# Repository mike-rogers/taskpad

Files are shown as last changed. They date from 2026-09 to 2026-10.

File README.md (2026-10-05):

# TaskPad

**[Project page & browser flasher](https://mike-rogers.github.io/taskpad/)** ·
install the integration via HACS custom repository
(`https://github.com/mike-rogers/taskpad`) · printable case in [`stl/`](stl/) ·
MIT licensed

A small desk gadget that nags you (politely) about periodic chores — change
the furnace filter, dose the dog, swap smoke detector batteries. Home
Assistant is the source of truth; this device displays what's coming due and
lets you check things off with a button.

The device talks MQTT and announces itself with MQTT discovery, so it appears
in HA as a proper device (with online/offline connectivity and a
last-completed-task sensor) — no API tokens involved.

Hardware:

- SparkFun Pro Micro ESP32-C3
- 2.8" 240x320 ST7789 TFT (SPI)
- Two momentary buttons, and optionally the Adafruit ANO rotary encoder on
  its I2C seesaw adapter (product 5740)

## Wiring (defaults, changeable in menuconfig)

| LCD pin | ESP32-C3 GPIO |
|---|---|
| VCC | 3V3 |
| GND | GND |
| SCL / SCK | 6 |
| SDA / MOSI| 7 |
| CS | 10 |
| DC | 4 |
| RES / RST | 5 |
| BLK | 3 |

| Button | GPIO |
|---|---|
| Done (complete) | 1 → button → GND |
| Down (select) | 9 (onboard BOOT button) |

| ANO adapter (STEMMA QT) | ESP32-C3 GPIO |
|---|---|
| VIN (red) | 3V3 |
| GND (black) | GND |
| SDA (blue) | 0 |
| SCL (yellow) | 2 |

The encoder is detected at boot; without it the device runs on the two
buttons alone. Wheel and up/down move the selection, center press
completes, center long-press marks blocked.

## Home Assistant setup

Terminology note: recent HA renamed "Add-ons" to **Apps**, and the config
directory File Editor shows is **`homeassistant/`** (formerly `/config` —
same place, new name; HA core itself still calls it `/config` internally,
which is why file paths below use that form).

Tasks live in a native HA **to-do list**, so adding and editing chores
happens on the To-do sidebar page — no YAML edits per task. Completions are
appended to a permanent log file, `/config/taskpad_history.log`.

1. Install the **File Editor** app (Settings → Apps → App Store) so you can
   edit YAML files, and the **Mosquitto broker** app if it isn't already
   installed. Once Mosquitto is running, Settings → Devices & Services will
   offer to set up the MQTT integration — accept it.
2. Create a dedicated HA user (e.g. `taskpad`) under Settings → People →
   Users; the device logs into the broker with it.
3. In File Editor, open `configuration.yaml` (in the root `homeassistant/`
   directory) and add this block at the top, above `default_config:`:

   ```yaml
   homeassistant:
     packages: !include_dir_named packages
     allowlist_external_dirs:
       - /config
   ```

   (The allowlist is what permits the File integration to write the history
   log. It must be in place, and HA restarted, BEFORE you set up the File
   integration in step 6 — the integration validates the path when you add
   it, and rejects it with "Access to the selected file path is not
   allowed" otherwise.)
4. Create the `packages` folder first using File Editor's New Folder button —
   naming a new file `packages/taskpad.yaml` does NOT auto-create the folder;
   it errors instead. Then create `taskpad.yaml` inside it and paste in the
   contents of `ha/taskpad.yaml` from this repo.
5. Validate with Developer Tools → YAML → Check configuration, then restart
   HA.
6. Add two integrations under Settings → Devices & Services → Add
   integration:
   - **Local to-do**: create a list named `TaskPad`. Confirm its entity id
     is `todo.taskpad` (Developer Tools → States); the package references
     that id.
   - **File**: choose the notification service type, file path
     `/config/taskpad_history.log`, timestamps enabled. The integration
     names the entity generically (`notify.file`), so rename it: Settings →
     Devices & Services → Entities → `notify.file` → settings (gear icon) →
     set Entity ID to `notify.taskpad_history`.
7. Add your chores on the **To-do** sidebar page: name, first due date, and
   the repeat interval in the description field — `interval: 90` (days),
   `interval: 2w`, `interval: 3m`, or `interval: 1y`. Anything missing or
   unparseable falls back to 30 days.

## Custom integration (replaces the package)

`custom_components/taskpad/` supersedes the YAML package, Local to-do, and
File integration: an integration-owned `todo.taskpad` entity with
structured intervals, direct MQTT handling (no automations), the same
completion-relative rescheduling and history log, a `taskpad.complete`
service, and a `taskpad_completed` event. Ticking the checkbox on the
To-do card runs the full completion flow (unlike the package setup).

The integration also serves a dashboard card: add a card of type
`custom:taskpad-card` to any dashboard for the full editor — task list
with urgency colors, complete/block/edit buttons, and a create/edit form
(name, first due date, periodicity value + days/weeks/months, and the
dependency task spawned on long-press). The same operations exist as
typed services (`taskpad.add_task`, `taskpad.update_task`,
`taskpad.block`, `taskpad.complete`) for automations and Developer Tools.

Install: copy the folder to `custom_components/taskpad/` in the HA config
directory, restart HA, then Settings → Devices & Services → Add
integration → TaskPad. Use the import field to pull your open items from
the existing list, then delete the old Local to-do list and remove the
package's `script:`/`automation:` blocks (double handlers = double
successors). Tip: the Samba share app makes copying the folder a
drag-and-drop from a mounted network share.

The package setup steps below describe the pre-integration architecture;
they're kept as documentation of the fallback path, not required setup.

## Build & flash

```sh
idf.py set-target esp32c3
idf.py menuconfig   # TaskPad Configuration: Wi-Fi + pins (broker config
                    # is pushed by the HA integration during adoption)
idf.py build flash monitor
```

Broker setup happens over the network, not at compile time: the device
advertises `_taskpad._tcp` via mDNS and serves a small local API
(`GET /api/info`, `POST /api/config`). Home Assistant discovers it
("New device found: TaskPad"), and the integration's adoption step pushes
the MQTT broker URI and credentials, which the device stores in NVS and
reboots onto. Re-adopt any time (credential rotation, new broker) via the
integration's Configure → "Adopt device" menu. Use an IP address for the
broker URI — the device can't resolve `.local` names.

`sdkconfig` holds your Wi-Fi password, and is gitignored.

## Behavior

- HA publishes the task list to the retained `taskpad/tasks` topic whenever
  the to-do list changes (plus hourly, to catch due-date edits); the device
  gets updates instantly and current state on every reconnect — no polling.
- Shows tasks due within 14 days (configurable); overdue tasks always show.
- Row color by urgency: green → yellow (≤7 days) → orange (≤2 days) →
  red (overdue).
- Long-pressing Done (~1.5s) marks the selected task **blocked**: a linked
  one-shot "Prep: …" item is created due today (rename it in HA to what the
  prep actually is, e.g. "Call vet about flea meds"), and the blocked task
  renders muted on the display. Completing the prep task auto-unblocks the
  parent; completing the parent directly auto-closes the orphaned prep.
- BOOT moves the selection; the Done button publishes to `taskpad/complete`,
  which runs `script.taskpad_complete`: the to-do item is closed out (it
  stays in the completed pile as a visual record), a successor item is
  created due **completion date + interval**, and a timestamped line is
  appended to `/config/taskpad_history.log` — the permanent record, immune
  to HA's ~10-day recorder purge.
- To complete a chore from HA instead of the device, run
  `script.taskpad_complete` (e.g. from a dashboard button) with the item's
  name. Ticking the checkbox on the To-do page completes the item WITHOUT
  scheduling the next occurrence or logging.
- Availability via MQTT last-will: unplug the device and its Connectivity
  entity in HA goes off.

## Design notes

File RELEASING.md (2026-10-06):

# Releasing TaskPad

## Firmware release (public, via CI)

1. Bump `TASKPAD_FW_VERSION` in `main/fw_version.h`.
2. Commit, then tag and push:

   ```sh
   git tag vX.Y.Z
   git push origin main --tags
   ```

3. CI (`.github/workflows/firmware.yml`) builds against ESP-IDF v6.0 and
   attaches three assets to the GitHub release:
   - `taskpad.bin` — the OTA application image
   - `taskpad-factory.bin` — esptool-merged full-flash image
   - `taskpad.zip` — the integration **with the matching firmware baked
     in**; HACS installs this (`zip_release` in `hacs.json`), so HACS
     users get device updates on the HA device page automatically after
     updating the integration
4. The release publish triggers `.github/workflows/pages.yml`, which
   redeploys the project page and browser flasher with the new factory
   image. (The binary is copied into the Pages artifact deliberately:
   GitHub release assets don't send CORS headers, so ESP Web Tools can't
   fetch them cross-origin.)

## Updating your own device (local dev builds, no CI)

For a HACS-managed install, the normal path is: update TaskPad in HACS →
restart → Install on the device page. The steps below are for pushing a
locally built firmware without cutting a release:

1. `idf.py build`
2. `./scripts/release_firmware.sh` — stages `taskpad.bin` + `version.txt`
   into `custom_components/taskpad/firmware/`
3. Copy `custom_components/taskpad/firmware/*` to the HA config share
   (plain `cp`, not Finder — the Samba add-on vetoes `._*` metadata files
   and Finder copies fail with error -8062).
4. Home Assistant → TaskPad device page → the Firmware entity offers the
   update (poll is ~15 min; force with the `homeassistant.update_entity`
   action) → Install. The device pulls, flashes the idle OTA slot, and
   reboots; a boot that never reaches MQTT rolls back automatically.

## Integration release

1. Bump `version` in `custom_components/taskpad/manifest.json` **and**
   `VERSION` in `custom_components/taskpad/const.py` (they must match —
   the versioned Lovelace resource URL busts card caches).
2. Local install: copy the changed files to the share and restart HA.
3. HACS installs pick up new tags/default-branch commits via HACS's
   normal update flow.

## Invariants worth knowing

- Firmware and integration versions are independent; the update entity
  compares the device's reported version (retained `taskpad/status`)
  against `firmware/version.txt`, and only offers an update when the
  served `taskpad.bin` actually exists next to it.
- The OTA slots are 1984KB each and the image is ~1.8MB (~10% headroom).
  Budget flash before adding large components.
- A commit that shouldn't trigger the firmware CI can include `[skip ci]`
  in its message.

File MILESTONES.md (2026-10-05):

# TaskPad Milestones

Each milestone leaves the whole system working end-to-end before the next
begins.

## M0 — Baseline (done, 2026-09-24)

ESP-IDF firmware (ESP32-C3 + ST7789, LVGL, MQTT) plus a Home Assistant YAML
package: Local to-do list backend, completion-relative rescheduling,
permanent history log via the File integration, MQTT discovery device.
Working: button → todo close-out → successor → history line → display
refresh.

## M1 — Custom integration core (done, 2026-09-24)

Replace the YAML package, Local to-do, and File integration with
`custom_components/taskpad/`:

- [x] Integration-owned `todo.taskpad` entity backed by `.storage`
      (structured `interval_days` per item instead of description-string
      parsing being the source of truth; `interval: N[d|w|m|y]` in the
      description remains the input method from the To-do card)
- [x] Config flow (topic prefix, log path, default interval) + options flow
- [x] MQTT: subscribe `taskpad/complete` directly, publish retained
      `taskpad/tasks` on every change (no automations)
- [x] Completion logic in Python: close item, create successor at
      completion date + interval, append history line, fire
      `taskpad_completed` bus event (logbook visibility)
- [x] Ticking the checkbox in the To-do card triggers the SAME completion
      flow (the entity intercepts the status change — the old "don't touch
      the checkbox" rule dies here)
- [x] `taskpad.complete` service (name or uid)
- [x] One-time import from the existing Local to-do list
- [x] Clean uninstall: `async_remove_entry` deletes storage and clears the
      retained tasks topic
- [x] Migration: after verification, remove the package automations/script
      and the Local to-do list

Firmware: unchanged.

## M2 — Blocked / prerequisite tasks (done, 2026-09-24)

- [x] Firmware: long-press detection on Done (and later the ANO center
      button); publishes `{"task_id": ...}` to `taskpad/blocked`
- [x] Integration: creates a linked one-shot prep item ("Prep: <name>", due
      today, no interval), marks the parent blocked, stores the link by uid
- [x] Completing the prep item auto-unblocks the parent; completing the
      parent directly auto-closes the orphaned prep item
- [x] Published task list gains a `blocked` flag; device renders blocked
      items distinctly
- [x] History log records blocked/unblocked transitions

## M2.5 — Task editor: typed services + custom card (done, 2026-09-26)

- [x] Structured periodicity stored as value + unit (days/weeks/months);
      per-task dependency text (`prep_text`) used as the spawned prep item's
      name; storage migration from interval_days-only items
- [x] Services with typed selectors: `taskpad.add_task` (name, first due
      date defaulting to today + period, value + unit, dependency text),
      `taskpad.update_task`, `taskpad.block`
- [x] Task metadata exposed as `todo.taskpad` attributes for the frontend
- [x] `custom:taskpad-card` (vanilla JS, served + auto-registered by the
      integration): task list with urgency colors, blocked/prep rendering,
      complete/block/edit buttons, and a create/edit form with the fields
      above, prefilled on edit
- [x] Legacy `interval:` description parsing retained as fallback input

## M3 — Discovery & adoption (done, 2026-09-26)

- [x] Firmware: mDNS advertisement (`_taskpad._tcp`, TXT: id + version) and
      a small local HTTP endpoint that accepts broker config on first boot;
      config persisted to NVS
- [x] Integration: zeroconf discovery in the manifest → "New device found"
      card → config flow pushes broker credentials to the device
- [x] Remove Wi-Fi/broker secrets from menuconfig (Wi-Fi still via
      menuconfig until M4)
- [x] Remove device-side MQTT discovery configs (the integration owns the
      device registration); firmware sheds the discovery payloads

Note: adoption verified working on first try. Auto-discovery initially
appeared broken; a Linux host resolving both homeassistant.local and the
device disproved the network-filtering theory (the Mac's failures were
macOS Local Network permission gating) and pointed at the config flow
reading the removed ZeroconfServiceInfo.host attribute — fixed to
ip_address. Adoption by IP via Configure -> Adopt device works
regardless of discovery. Full fresh-install path (delete entry ->
discovered card -> adopt) verified end-to-end 2026-09-27; note that HA
only re-surfaces the discovery after a fresh device announcement, so a
device reboot may be needed when re-adding. Discovery flows are
suppressed by design while an entry exists (single_config_entry).

## M4 — Improv Wi-Fi provisioning (BLE) (done, 2026-09-27)

- [x] Firmware: Improv-over-BLE per the published spec; factory-fresh
      device is provisioned from the HA companion app, then M3 discovery
      takes over (self-contained `improv_ble` module, reusable in other
      gadgets: NimBLE GATT service + advertising + RPC, project-specific
      behavior injected via a connect callback)
- [x] Wi-Fi credentials live in NVS; menuconfig values remain an optional
      dev-only fallback (empty by default) rather than being removed

Note: verified with the HA companion app end-to-end (including
fail-fast retry on mistyped credentials). Wi-Fi passwords must be
typed on the phone: mobile OSes expose stored Wi-Fi credentials to
no app, so no provisioning flow can prefill them.

## M5 — OTA updates (done, 2026-09-27)

- [x] Partition relayout: two OTA app slots (verify headroom for the
      ~1.4MB image within 4MB flash)
- [x] Firmware: `esp_https_ota` pull, rollback on failed boot
- [x] Integration: `update` entity on the device page serving/pointing to
      firmware binaries

Note: verified with a live 0.8.0 -> 0.8.1 update installed from the
HA device page. Slot headroom is 14% at the current 1.75MB image;
budget flash before adding large features. Release ritual:
idf.py build -> scripts/release_firmware.sh -> copy firmware/* to
the HA share -> Install in HA.

## M6 — Stretch

- [x] Adafruit ANO rotary encoder input backend (I2C seesaw) behind the
      existing input abstraction (done 2026-10-05: detected at boot on
      SDA=GPIO0/SCL=GPIO2, wheel + up/down move the selection, center
      press/long-press = Done/blocked; GPIO buttons still work; verified
      on hardware; app slot headroom now 10%)
- [x] HACS packaging and publication (done 2026-09-27:
      github.com/mike-rogers/taskpad, MIT; CI builds firmware and
      publishes releases; browser flasher + project page at
      mike-rogers.github.io/taskpad; case STLs in stl/)
- [ ] Lovelace dashboard example

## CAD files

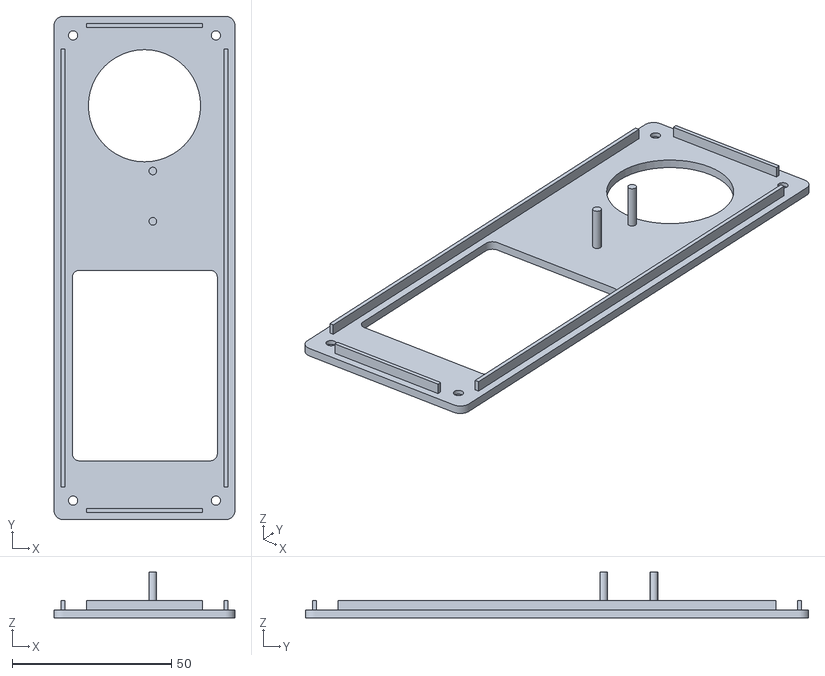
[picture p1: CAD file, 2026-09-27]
stl/taskpad_lid.stl
56.8 x 158.0 x 14.3

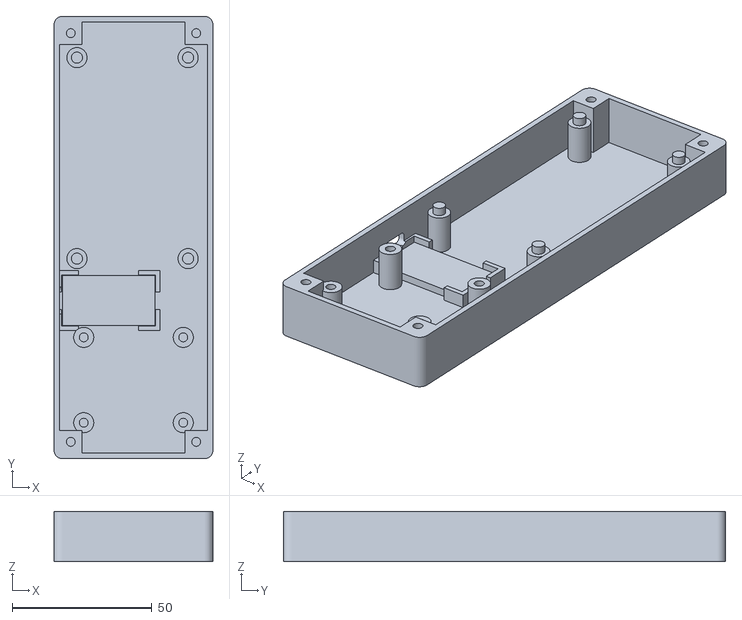
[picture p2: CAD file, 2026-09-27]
stl/taskpad_base.stl
56.8 x 158.0 x 18.0

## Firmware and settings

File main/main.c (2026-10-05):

#include <stdbool.h>
#include <stdlib.h>
#include <time.h>

#include "freertos/FreeRTOS.h"
#include "freertos/task.h"
#include "freertos/queue.h"
#include "esp_log.h"
#include "esp_event.h"
#include "esp_netif.h"
#include "esp_netif_sntp.h"
#include "nvs_flash.h"

#include "esp_mac.h"
#include "esp_ota_ops.h"

#include "wifi_conn.h"
#include "taskpad_mqtt.h"
#include "device_cfg.h"
#include "adopt_server.h"
#include "improv_ble.h"
#include "events.h"
#include "ui.h"
#include "input.h"

static const char *TAG = "taskpad";

// With no events, wake hourly so days-left rolls over at midnight.
#define IDLE_TICKS pdMS_TO_TICKS(60 * 60 * 1000)

static task_item_t s_tasks[TASKS_MAX];
static size_t s_count;
static size_t s_selected;

static void sync_time(void)
{
    setenv("TZ", CONFIG_TASKPAD_TZ, 1);
    tzset();
    esp_sntp_config_t cfg = ESP_NETIF_SNTP_DEFAULT_CONFIG("pool.ntp.org");
    ESP_ERROR_CHECK(esp_netif_sntp_init(&cfg));
    if (esp_netif_sntp_sync_wait(pdMS_TO_TICKS(15000)) != ESP_OK) {
        ESP_LOGW(TAG, "SNTP sync timed out; due dates may be wrong until it lands");
    }
}

// Improv hands us candidate credentials; trial them and persist on success.
static bool improv_try_connect(const char *ssid, const char *password)
{
    ui_set_status("Trying Wi-Fi...");
    if (!wifi_conn_try(ssid, password, 15000)) {
        ui_set_status("Wi-Fi failed - try again from the app");
        return false;
    }
    if (device_cfg_save_wifi(ssid, password) != ESP_OK) {
        ESP_LOGE(TAG, "could not persist Wi-Fi credentials");
    }
    return true;
}

static void refresh(void)
{
    s_count = taskpad_mqtt_get_tasks(s_tasks, TASKS_MAX);
    if (s_selected >= s_count) {
        s_selected = 0;
    }
    ui_show_tasks(s_tasks, s_count, s_selected);
}

static void set_status_time(const char *prefix)
{
    time_t now = time(NULL);
    struct tm tm;
    localtime_r(&now, &tm);
    char buf[40];
    snprintf(buf, sizeof(buf), "%s %02d:%02d", prefix, tm.tm_hour, tm.tm_min);
    ui_set_status(buf);
}

void app_main(void)
{
    esp_err_t err = nvs_flash_init();
    if (err == ESP_ERR_NVS_NO_FREE_PAGES || err == ESP_ERR_NVS_NEW_VERSION_FOUND) {
        ESP_ERROR_CHECK(nvs_flash_erase());
        err = nvs_flash_init();
    }
    ESP_ERROR_CHECK(err);
    ESP_ERROR_CHECK(esp_netif_init());
    ESP_ERROR_CHECK(esp_event_loop_create_default());

    ui_init();

    static device_cfg_t cfg;
    bool provisioned = device_cfg_load(&cfg);

    wifi_conn_init();

    // Wi-Fi credentials: NVS (Improv-provisioned) first, then the optional
    // menuconfig dev fallback, else BLE provisioning via the HA app.
    const char *ssid = cfg.wifi_ssid[0] ? cfg.wifi_ssid
                                        : CONFIG_TASKPAD_WIFI_SSID;
    const char *pass = cfg.wifi_ssid[0] ? cfg.wifi_pass
                                        : CONFIG_TASKPAD_WIFI_PASSWORD;
    if (ssid[0]) {
        ui_set_status("Connecting to Wi-Fi...");
        while (!wifi_conn_try(ssid, pass, 20000)) {
            ui_set_status("Wi-Fi retrying...");
        }
    } else {
        uint8_t mac[6];
        static char name[24];
        esp_read_mac(mac, ESP_MAC_WIFI_STA);
        snprintf(name, sizeof(name), "taskpad-%02x%02x%02x", mac[3], mac[4],
                 mac[5]);
        ui_set_status("Set up Wi-Fi with the Home Assistant app");
        improv_ble_start(name, improv_try_connect);
        improv_ble_wait_provisioned();
        improv_ble_stop();
        ui_set_status("Wi-Fi connected");
    }

    ui_set_status("Syncing time...");
    sync_time();
    adopt_server_start(provisioned);

    if (!provisioned) {
        // A successful adoption POST saves the config and reboots us.
        ESP_LOGI(TAG, "unprovisioned: waiting for adoption");
        ui_set_status("Ready to adopt: add TaskPad in Home Assistant");
        for (;;) {
            vTaskDelay(portMAX_DELAY);
        }
    }

    QueueHandle_t queue = xQueueCreate(16, sizeof(app_event_t));
    input_init(queue);

    ui_set_status("Connecting to MQTT...");
    taskpad_mqtt_start(queue, &cfg);

    for (;;) {
        app_event_t evt;
        if (xQueueReceive(queue, &evt, IDLE_TICKS) != pdTRUE) {
            refresh(); // recompute days-left across midnight
            continue;
        }

        switch (evt) {
        case APP_EVT_BTN_DOWN:
            if (s_count > 0) {
                s_selected = (s_selected + 1) % s_count;
                ui_show_tasks(s_tasks, s_count, s_selected);
            }
            break;

        case APP_EVT_BTN_UP:
            if (s_count > 0) {
                s_selected = (s_selected + s_count - 1) % s_count;
                ui_show_tasks(s_tasks, s_count, s_selected);
            }
            break;

        case APP_EVT_BTN_DONE:
            if (s_count > 0) {
                if (taskpad_mqtt_publish_complete(s_tasks[s_selected].id) == ESP_OK) {
                    // HA reschedules and republishes the retained task list,
                    // which arrives as APP_EVT_TASKS_UPDATED.
                    ui_set_status("Completing...");
                } else {
                    ui_set_status("Complete failed");
                }
            }
            break;

        case APP_EVT_BTN_DONE_LONG:
            if (s_count > 0) {
                if (taskpad_mqtt_publish_blocked(s_tasks[s_selected].id) == ESP_OK) {
                    ui_set_status("Marked blocked - prep task created");
                } else {
                    ui_set_status("Block failed");
                }
            }
            break;

        case APP_EVT_TASKS_UPDATED:
            refresh();
            set_status_time("Updated");
            break;

        case APP_EVT_CONN_UP:
            ui_set_status("Connected");
            // A healthy MQTT connection is our post-OTA health check: only
            // now does a freshly flashed image escape bootloader rollback.
            esp_ota_mark_app_valid_cancel_rollback();
            break;

        case APP_EVT_CONN_DOWN:
            ui_set_status("MQTT disconnected");
            break;
        }
    }
}

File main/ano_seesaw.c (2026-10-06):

#include "ano_seesaw.h"

#include "driver/i2c_master.h"
#include "esp_log.h"
#include "esp_rom_sys.h"
#include "freertos/FreeRTOS.h"
#include "freertos/task.h"

static const char *TAG = "ano";

#define ANO_ADDR 0x49
#define ANO_PRODUCT_ID 5740
#define I2C_TIMEOUT_MS 20
// The seesaw needs time to stage a register before it can be read back.
#define READ_DELAY_US 250

// Seesaw module bases and registers (Adafruit seesaw protocol)
#define SS_STATUS 0x00
#define SS_STATUS_VERSION 0x02
#define SS_STATUS_SWRST 0x7F
#define SS_GPIO 0x01
#define SS_GPIO_DIRCLR_BULK 0x03
#define SS_GPIO_BULK 0x04
#define SS_GPIO_BULK_SET 0x05
#define SS_GPIO_PULLENSET 0x0B
#define SS_ENCODER 0x11
#define SS_ENCODER_DELTA 0x40

#define BUTTON_MASK (ANO_BTN_SELECT | ANO_BTN_UP | ANO_BTN_LEFT | \
                     ANO_BTN_DOWN | ANO_BTN_RIGHT)

static i2c_master_dev_handle_t s_dev;

static esp_err_t ss_write(uint8_t base, uint8_t reg, const uint8_t *data,
                          size_t len)
{
    uint8_t buf[6] = {base, reg};
    for (size_t i = 0; i < len; i++) {
        buf[2 + i] = data[i];
    }
    return i2c_master_transmit(s_dev, buf, 2 + len, I2C_TIMEOUT_MS);
}

static esp_err_t ss_read(uint8_t base, uint8_t reg, uint8_t *out, size_t len)
{
    esp_err_t err = ss_write(base, reg, NULL, 0);
    if (err != ESP_OK) {
        return err;
    }
    esp_rom_delay_us(READ_DELAY_US);
    return i2c_master_receive(s_dev, out, len, I2C_TIMEOUT_MS);
}

static esp_err_t ss_read_u32(uint8_t base, uint8_t reg, uint32_t *out)
{
    uint8_t b[4];
    esp_err_t err = ss_read(base, reg, b, sizeof(b));
    if (err == ESP_OK) {
        *out = (uint32_t)b[0] << 24 | (uint32_t)b[1] << 16 |
               (uint32_t)b[2] << 8 | b[3];
    }
    return err;
}

static esp_err_t ss_write_u32(uint8_t base, uint8_t reg, uint32_t v)
{
    uint8_t b[4] = {v >> 24, v >> 16, v >> 8, v};
    return ss_write(base, reg, b, sizeof(b));
}

bool ano_seesaw_init(int sda_pin, int scl_pin)
{
    i2c_master_bus_config_t bus_cfg = {
        .i2c_port = -1,
        .sda_io_num = sda_pin,
        .scl_io_num = scl_pin,
        .clk_source = I2C_CLK_SRC_DEFAULT,
        .glitch_ignore_cnt = 7,
        // The adapter has its own pull-ups; these keep an empty bus from
        // floating so the probe fails cleanly.
        .flags.enable_internal_pullup = true,
    };
    i2c_master_bus_handle_t bus;
    esp_err_t err = i2c_new_master_bus(&bus_cfg, &bus);
    if (err != ESP_OK) {
        ESP_LOGW(TAG, "I2C bus init failed: %s", esp_err_to_name(err));
        return false;
    }
    err = i2c_master_probe(bus, ANO_ADDR, I2C_TIMEOUT_MS);
    if (err != ESP_OK) {
        // NOT_FOUND = nothing acked; TIMEOUT = a line is stuck (shorted).
        ESP_LOGI(TAG, "no ANO encoder at 0x%02x (%s); buttons only",
                 ANO_ADDR, esp_err_to_name(err));
        i2c_del_master_bus(bus);
        return false;
    }

    i2c_device_config_t dev_cfg = {
        .dev_addr_length = I2C_ADDR_BIT_LEN_7,
        .device_address = ANO_ADDR,
        .scl_speed_hz = 100000,
    };
    ESP_ERROR_CHECK(i2c_master_bus_add_device(bus, &dev_cfg, &s_dev));

    uint8_t rst = 0xFF;
    ss_write(SS_STATUS, SS_STATUS_SWRST, &rst, 1);

    // The seesaw takes a variable time to come back from reset, so poll
    // for it rather than trusting a fixed delay.
    uint32_t version = 0;
    for (int attempt = 0; attempt < 20; attempt++) {
        vTaskDelay(pdMS_TO_TICKS(10));
        err = ss_read_u32(SS_STATUS, SS_STATUS_VERSION, &version);
        if (err == ESP_OK) {
            break;
        }
    }
    if (err != ESP_OK) {
        ESP_LOGW(TAG, "ANO encoder not responding after reset (%s)",
                 esp_err_to_name(err));
        return false;
    }
    // The upper half of the version register is the Adafruit product id.
    if ((version >> 16) != ANO_PRODUCT_ID) {
        ESP_LOGW(TAG, "seesaw at 0x%02x is product %lu, not the ANO (%d)",
                 ANO_ADDR, (unsigned long)(version >> 16), ANO_PRODUCT_ID);
        return false;
    }

    // Buttons are inputs with pull-ups (pressed = low).
    if (ss_write_u32(SS_GPIO, SS_GPIO_DIRCLR_BULK, BUTTON_MASK) != ESP_OK ||
        ss_write_u32(SS_GPIO, SS_GPIO_PULLENSET, BUTTON_MASK) != ESP_OK ||
        ss_write_u32(SS_GPIO, SS_GPIO_BULK_SET, BUTTON_MASK) != ESP_OK) {
        ESP_LOGW(TAG, "ANO button setup failed");
        return false;
    }

    // Discard any rotation accumulated before we started listening.
    int32_t discard;
    ano_seesaw_read_delta(&discard);

    ESP_LOGI(TAG, "ANO encoder ready");
    return true;
}

esp_err_t ano_seesaw_read_buttons(uint32_t *pressed)
{
    uint32_t levels;
    esp_err_t err = ss_read_u32(SS_GPIO, SS_GPIO_BULK, &levels);
    if (err == ESP_OK) {
        *pressed = ~levels & BUTTON_MASK;
    }
    return err;
}

esp_err_t ano_seesaw_read_delta(int32_t *delta)
{
    uint32_t raw;
    esp_err_t err = ss_read_u32(SS_ENCODER, SS_ENCODER_DELTA, &raw);
    if (err == ESP_OK) {
        // The seesaw counts counter-clockwise as positive.
        *delta = -(int32_t)raw;
    }
    return err;
}

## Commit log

2026-09-24 M0 baseline: ESP32-C3 TaskPad firmware + Home Assistant package
    Firmware (ESP-IDF 6.0): LVGL 9 UI on a 2.8" ST7789, event-driven MQTT
    client (retained task list in, completions out, LWT availability, HA
    discovery), debounced GPIO input behind an event abstraction.
    HA package: native to-do list backend with completion-relative
    rescheduling (close item + create successor at today + interval) and a
    permanent history log via the File integration.
    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
    [partitions.csv]
2026-09-24 M1: TaskPad custom integration core
    custom_components/taskpad: config + options flow, storage-backed
    todo.taskpad entity with structured per-item intervals (interval: N[dwmy]
    in descriptions remains the input method), direct MQTT subscribe/publish
    replacing both package automations, completion flow in Python (close item,
    create successor at completion date + interval, append history log line,
    fire taskpad_completed event), taskpad.complete service, one-time import
    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
2026-09-24 Mark M1 verified on live HA; update docs
    Integration confirmed working end-to-end on HA 2026.9.3: import from
    Local to-do, device completion cascade (successor + history log + event +
    retained republish), checkbox completion, and migration cleanup done.
2026-09-24 M2: blocked/prerequisite tasks
    Integration (0.4.0): taskpad/blocked topic creates a linked one-shot
    'Prep: <task>' item due today and marks the parent blocked; completing the
    prep auto-unblocks the parent, completing the parent auto-closes orphaned
    preps, and deleting a prep unblocks its parent. Published task list gains
    a 'blocked' flag; history log records block/unblock; taskpad_blocked event.
    Firmware: long-press (1.5s) on Done publishes the block request (short
    press now fires on release so the two are distinguishable); blocked rows
    render muted with a pause marker.
    Not yet verified on live HA/hardware.
    [input.c, main.c]
2026-09-24 Fix blocked-row marker (missing symbol glyphs); mark M2 verified
    The Kconfig-built Montserrat fonts lack the FontAwesome symbol glyphs, so
    LV_SYMBOL_PAUSE rendered as tofu boxes. Blocked rows now parenthesize the
    days text instead; the muted colors carry the meaning.
    M2 verified on live HA + hardware 2026-09-24 (block flow, auto-unblock,
    auto-close, display rendering).
    [ui.c]
2026-09-24 M2.5: task editor - typed services and custom dashboard card
    Integration (0.5.0): periodicity stored structured (value + days/weeks/
    months unit) with migration from interval_days-only items; per-task
    dependency text (prep_text) becomes the spawned prep item's name;
    taskpad.add_task / update_task / block services with typed selectors;
    task metadata exposed as todo.taskpad attributes.
    Frontend: custom:taskpad-card (vanilla JS, served and auto-registered by
    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
2026-09-26 taskpad-card v0.5.2: survive hass-before-setConfig ordering
    In rebuild-after-late-define flows HA can assign hass before setConfig;
    the render path then dereferenced undefined config and threw, which HA
    surfaces as an intermittent 'configuration error' card. Guard both
    orderings and re-render once config arrives.
2026-09-26 taskpad-card v0.5.3: self-heal stranded error placeholders
    On hard refresh the module can register in the window between HA creating
    the 'element doesn't exist' placeholder and attaching it, so the
    whenDefined -> ll-rebuild event fires before anyone is listening and the
    placeholder is stranded. After registering, sweep the (shadow) DOM for
    hui-error-card instances and re-dispatch ll-rebuild at intervals.
2026-09-26 M3: discovery and adoption
    Firmware (0.7.0): broker config moves from menuconfig to NVS, pushed over
    a local HTTP endpoint (GET /api/info, POST /api/config -> save + reboot);
    mDNS advertisement _taskpad._tcp with id/version/provisioned TXT records;
    unprovisioned devices wait on-screen for adoption; device-side MQTT
    discovery configs removed and stale retained configs cleared on connect.
    Integration (0.7.0): zeroconf discovery ('New device found' card) with an
    adoption step that pushes broker credentials (defaults to HA's own IP for
    the broker URI); discovery on an existing install stores the device host
    and re-adoption lives in Configure -> Adopt device; connectivity
    binary_sensor now provi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
2026-09-27 Disable Wi-Fi modem power save for reliable mDNS
    Device answers TCP but drops/delays UDP multicast under the default
    modem sleep, which makes zeroconf discovery flaky. Mains-powered desk
    device: WIFI_PS_NONE is the right trade (also snappier MQTT).
2026-09-27 Fix zeroconf discovery: ZeroconfServiceInfo.host was removed from HA
    The discovery step read discovery_info.host, an attribute modern HA no
    longer provides, so every discovery fired an AttributeError and died
    silently while adoption (options flow) worked fine. Use ip_address with
    a host fallback. Also mark M3 verified and correct the milestone note:
    a Linux host resolves both homeassistant.local and the device, so the
    earlier LAN-multicast-filtering theory was wrong (the Mac's failures
    were macOS Local Network permission gating).
2026-09-27 M3 fully verified: fresh-install discovery + adoption end-to-end
    Delete entry -> discovered card (after a device reboot provides a fresh
    announcement) -> adopt from the card -> device reprovisioned. Task store
    backed up and restored across the test.
2026-09-27 M4: Improv Wi-Fi provisioning over BLE
    New self-contained improv_ble module (NimBLE): the published Improv BLE
    GATT service with state/error/RPC characteristics, advertising with the
    0x4677 service data the HA companion app scans for, RPC parsing with
    checksums, and a redirect URL built from the device IP. Project-specific
    behavior is injected via a connect callback, so future gadgets can lift
    the module unchanged.
    Wi-Fi rework: wifi_conn_init + wifi_conn_try(ssid, pass, timeout) with
    auto-reconnect enabled only after a successful join, so bad credentials
    from the app fail fast with in-app feedback. Credential precedence:
    NVS (Improv) > menuconfig (dev fallback, empty by default) > BLE
    prov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
    [main.c]
2026-09-27 M5: OTA updates
    Firmware (0.8.0): dual 1984KB OTA slots (repartition requires one final
    erase-flash + reprovision), esp_https_ota pull triggered by a URL
    published to taskpad/ota, retained taskpad/status reporting the running
    version, bootloader rollback with health marked on first MQTT connect,
    and a stop-guard so late BLE callbacks can't re-arm advertising during
    Improv teardown (fixes spurious adv_set_fields rc=30 after success).
    Integration (0.8.0): firmware update entity (installed from the status
    topic, latest from firmware/version.txt, Install publishes the download
    URL built from HA's local IP) and the binary served at
    /taskpad_files/firmware.bin. scripts/release_firmware.sh stages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
    [partitions.csv]
2026-09-27 Mark M5 verified: OTA 0.8.0 -> 0.8.1 installed from the HA device page
2026-09-27 Go public: MIT license, HACS packaging, CI, flasher site, case STLs
    - LICENSE (MIT) and hacs.json for HACS custom-repository installs
    - manifest.json: real repository URLs, issue tracker, @mike-rogers
    - update entity: no latest_version unless the served binary exists (git
    installs track version.txt but not the 1.7MB taskpad.bin)
    - GitHub Actions: ESP-IDF v6.0 build on push/PR; tagged releases get
    taskpad.bin plus an esptool-merged taskpad-factory.bin
    - GitHub Pages workflow + site: project story, hardware table, HACS and
    wiring docs, printable case STLs, and an ESP Web Tools browser flasher
    fed by the latest release's factory image
    - stl/: printable case (base + lid)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
    [taskpad_base.stl, taskpad_lid.stl]
2026-09-27 0.8.2: ship matching firmware inside the HACS package
    hacs.json switches to zip_release: CI now packs the integration together
    with the firmware it just built (taskpad.zip) and HACS installs that, so
    users get device updates on the HA device page after each integration
    update - no manual staging. Pages instructions gain the HACS bootstrap
    (Get HACS add-on) and a one-click my.home-assistant repository link.
    RELEASING.md updated; local staging is now a dev-only path.
2026-10-05 M6: Adafruit ANO rotary encoder over I2C seesaw
    Polls the ANO adapter (product 5740, 0x49) on SDA=GPIO0/SCL=GPIO2
    alongside the GPIO buttons and posts the same input events: wheel and
    up/down step the selection (new APP_EVT_BTN_UP), center press/long-press
    complete/block. Detected at boot by product id; absent means buttons only.
2026-10-06 ANO: poll for the seesaw after reset; name the I2C error on failure
    A fixed 50ms wait after soft reset isn't guaranteed, so retry the
    version read (as Adafruit's library does). Probe and bus failures now
    log the esp_err name: NOT_FOUND vs TIMEOUT separates an absent encoder
    from a shorted line, which is how an SCL-to-3V3 short was found.
    [ano_seesaw.c]
2026-10-06 0.9.0: Adafruit ANO rotary encoder support
    Optional ANO encoder on its I2C seesaw adapter (SDA=GPIO0, SCL=GPIO2):
    wheel and up/down move the selection, center press/long-press complete
    and block. Detected at boot; the GPIO buttons keep working either way.
